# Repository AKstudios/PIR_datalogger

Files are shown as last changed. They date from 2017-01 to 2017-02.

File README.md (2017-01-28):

# PIR data logger
A motion/activity data logger that stores time-stamped data on a microSD card whenever there is motion within 3-5m. Approximate battery life: 1-2 years depending on LiPo battery used.

<p align="center">
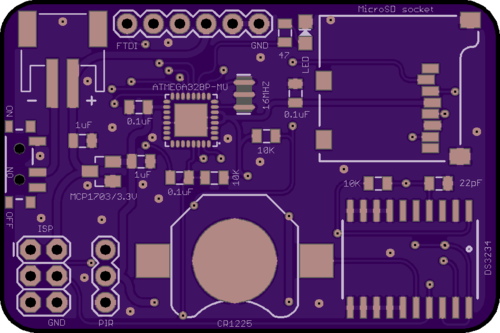
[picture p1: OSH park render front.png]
PIR datalogger - front
  
  <br></br>
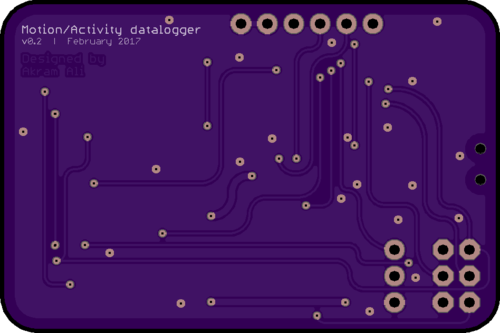
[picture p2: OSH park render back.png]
PIR datalogger - back
  
</p>

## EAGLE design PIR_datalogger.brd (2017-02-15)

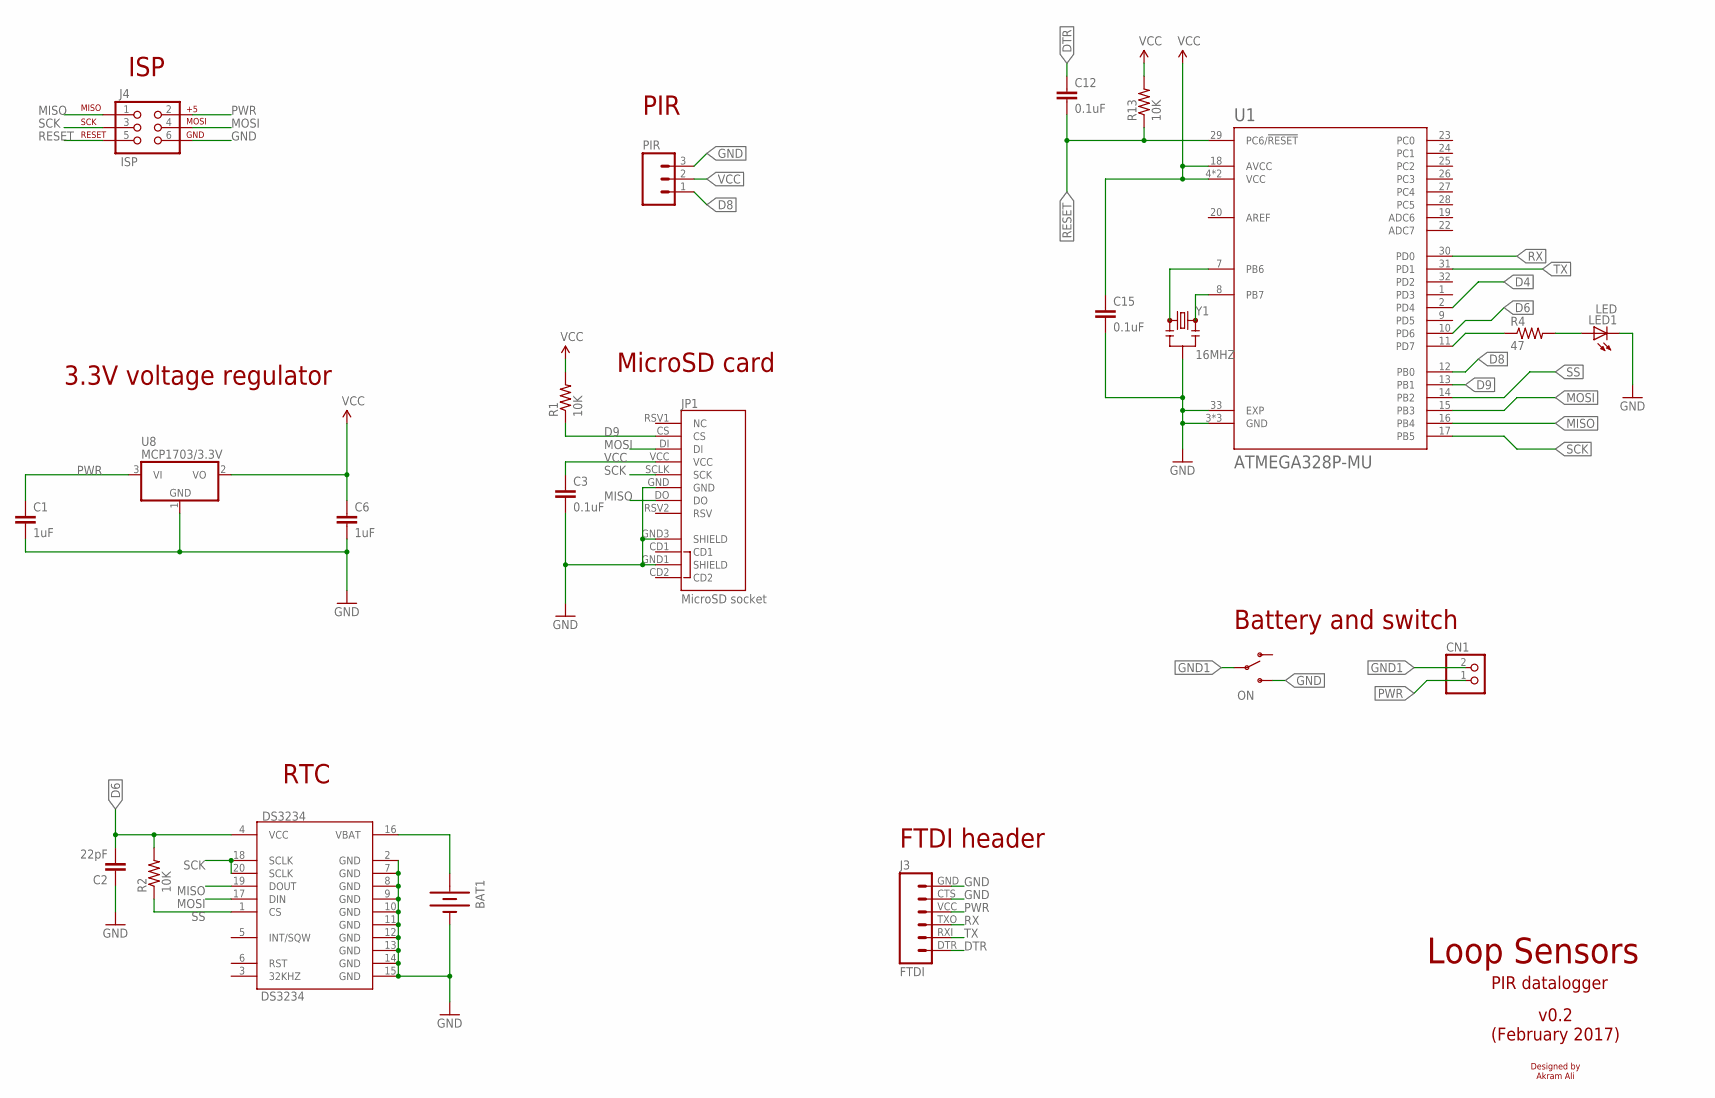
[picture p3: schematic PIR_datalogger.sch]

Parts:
BAT1: BATTERY12MM; BATTCON_12MM; MPN 3000
C1, C6: 1uF; 0805; MPN CC0805KKX7R7BB105
C2: 22pF; 0805; MPN AC0805KRX7R9BB104
C3, C12, C15: 0.1uF; 0805; MPN AC0805KRX7R9BB104
CN1: JST_2PIN-SMT-RA; JST-PH-2-SMT-RA
DS3234: DS3234; MPN DS3234S#
J3: FTDI; FTDI_BASIC
J4: ISP; 2X3
JP1: MicroSD socket; MICRO-SD-SOCKET-PP
LED1: LED; CHIPLED_0805; MPN 150080BS75000
ON: SWITCH-SPDT-SMD-A; SWITCH-SPST-SMD-A
PIR: M03PTH; 1X03
R1, R2, R13: 10K; 0805; MPN RC0805JR-0710KL
R4: 47; 0805; MPN RC0805JR-0747RL
U1: ATMEGA328P-MU; QFN50P500X500X100-33N
U8: MCP1703/3.3V; SOT23; MPN MCP1703T-2502E/CB
Y1: 16MHZ; RESONATOR-SMD; MPN CSTCE16M0V53-R0

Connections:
D4: U1.2 (PD4)
D6: C2.2, DS3234.4 (VCC), R2.2, U1.10 (PD6)
D8: PIR.1, U1.12 (PB0)
D9: JP1.CS, R1.1, U1.13 (PB1)
DTR: C12.1, J3.DTR (1)
GND: BAT1.GND (-), C1.2, C2.1, C3.2, C6.2, C15.2, DS3234.2 (GND), DS3234.7 (GND), DS3234.8 (GND), DS3234.9 (GND), DS3234.10 (GND), DS3234.11 (GND), DS3234.12 (GND), DS3234.13 (GND), DS3234.14 (GND), DS3234.15 (GND), J3.CTS (5), J3.GND (6), J4.6, JP1.GND, JP1.GND1 (SHIELD), JP1.GND3 (SHIELD), LED1.C, ON.3 (S), PIR.3, U1.3 (GND), U1.5 (GND), U1.21 (GND), U1.33 (EXP), U8.1 (GND), Y1.2
GND1: CN1.2 (1), ON.2
MISO: DS3234.19 (DOUT), J4.1, JP1.DO, U1.16 (PB4)
MOSI: DS3234.17 (DIN), J4.4, JP1.DI, U1.15 (PB3)
unnamed: R4.1, U1.11 (PD7)
unnamed: LED1.A, R4.2
unnamed: U1.8 (PB7), Y1.3
unnamed: U1.7 (PB6), Y1.1
unnamed: BAT1.PWR@1 (+), DS3234.16 (VBAT)
PWR: C1.1, CN1.1 (2), J3.VCC (4), J4.2, U8.3 (VI)
RESET: C12.2, J4.5, R13.1, U1.29 (PC6/!RESET)
RX: J3.TXO (3), U1.30 (PD0)
SCK: DS3234.18 (SCLK), DS3234.20 (SCLK), J4.3, JP1.SCLK (SCK), U1.17 (PB5)
SS: DS3234.1 (CS), R2.1, U1.14 (PB2)
TX: J3.RXI (2), U1.31 (PD1)
VCC: C3.1, C6.1, C15.1, JP1.VCC, PIR.2, R1.2, R13.2, U1.4 (VCC), U1.6 (VCC), U1.18 (AVCC), U8.2 (VO)

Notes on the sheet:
ISP
3.3V voltage regulator
Loop Sensors
PIR datalogger
v0.2 (February 2017)
Designed by Akram Ali
MicroSD card
RTC
PIR
FTDI header
Battery and switch

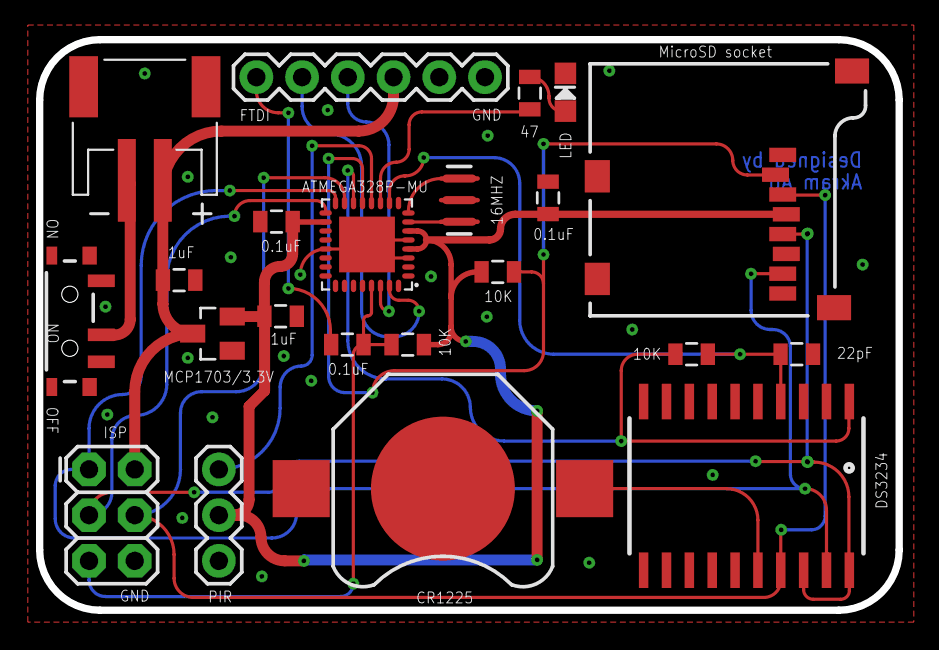
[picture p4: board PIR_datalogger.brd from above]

Board: 2 copper layers, 47.8 x 31.7 mm, 22 parts (0 on the bottom side), 20 nets.

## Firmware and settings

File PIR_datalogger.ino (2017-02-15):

//****************************************************************

// OSBSS PIR motion sensor datalogger - v0.01
// Last edited on March 30, 2015

//****************************************************************

#include <PowerSaver.h>
#include <DS3234lib3.h>
#include <SdFat.h>
#include <EEPROM.h>

// Global objects and variables   ******************************
char filename[15] = "log.csv";    // Filename. Format: "12345678.123". Cannot be more than 8 characters in length, contain spaces or start with a number

PowerSaver chip; // declare object for PowerSaver class
DS3234 RTC;      // declare object for DS3234 class
SdFat sd;        // declare object for SdFat class
SdFile myFile;     // declare object for SdFile class

#define POWER 4        // pin 4 supplies power to microSD card breakout
#define RTCPOWER 6     // pin 6 supplies power to DS3234 RTC breakout
#define LED 7          // pin 7 controls LED
int chipSelect = 9;       // pin 9 is micrSD card breakout CS pin
int state = 0;         // this variable stores the state of PIR sensor's output (either 1 or 0)

// ISR ****************************************************************
ISR(PCINT0_vect)  // Interrupt Service Routine for PCINT0 vector (pin 8)
{
  asm("nop");  // do nothing
}

// Main code ****************************************************************
void setup()
{
  Serial.begin(19200); // open serial at 19200 bps
  Serial.println("setup");
  delay(10);
  
  pinMode(POWER, OUTPUT); // set output pins
  pinMode(RTCPOWER, OUTPUT);
  pinMode(LED, OUTPUT);
  
  digitalWrite(POWER, HIGH);     // turn on SD card
  digitalWrite(RTCPOWER, HIGH);     // turn on RTC
  delay(1);                      // give some delay to ensure SD card is turned on properly
  
  if(!sd.begin(chipSelect, SPI_HALF_SPEED))  // initialize microSD card
  {
    SDcardError(3);
  }
  else
  {
    // open the file for write at end like the Native SD library
    if(!myFile.open(filename, O_RDWR | O_CREAT | O_AT_END))
    {
      SDcardError(2);
    }

    else
    {    
      myFile.println();
      myFile.println("Date/Time,Occupancy");
      myFile.println();
      myFile.close();
      
      digitalWrite(LED, HIGH);
      delay(10);
      digitalWrite(LED, LOW);
    }
  }
  chip.sleepInterruptSetup();    // setup sleep function & pin change interrupts on the ATmega328p. Power-down mode is used here
}

void loop()
{
  digitalWrite(POWER, LOW);  // turn off SD card
  digitalWrite(RTCPOWER, LOW);     // turn off RTC
  delay(1);
  
  chip.turnOffADC();  // turn off ADC to save power
  chip.turnOffSPI();  // turn off SPI bus to save power
  chip.turnOffWDT();  // turn off WatchDog timer. This doesn't work for Pro Mini (Rev 11); only works for Arduino Uno
  chip.turnOffBOD();

  chip.goodNight();    // put the processor in power-down mode
  
  // code will resume from here once the processor wakes up ============== //
  chip.turnOnADC();   // turn on ADC once the processor wakes up
  chip.turnOnSPI();   // turn on SPI bus once the processor wakes up
  delay(1);    // important delay to ensure SPI bus is properly activated
  
  digitalWrite(POWER, HIGH);  // turn on SD card
  digitalWrite(RTCPOWER, HIGH);     // turn on RTC
  delay(1);    // give some delay to ensure SD card is turned on properly
  
  RTC.checkDST(); // check and account for Daylight Savings Time in US
  
  printToSD(); // print data to SD card
}

void printToSD()
{
  String time = RTC.timeStamp();    // get date and time from RTC
  Serial.println(time);
  delay(10);
  
  if(!sd.begin(chipSelect, SPI_HALF_SPEED))
  {
    SDcardError(3);
  }
  else
  {
    if(!myFile.open(filename, O_RDWR | O_CREAT | O_AT_END))
    {
      SDcardError(2);
    }
  
    else
    {
      state = digitalRead(8); // read current state of PIR. 1 = movement detected, 0 = no movement.
      
      if(state == 1)
      {
        myFile.print(time);
        myFile.print(",");
        myFile.print("0");
        myFile.println();
        myFile.print(time);
        myFile.print(",");
        myFile.print("1");
      }
      else if(state == 0)
      {
        myFile.print(time);
        myFile.print(",");
        myFile.print("1");
        myFile.println();
        myFile.print(time);
        myFile.print(",");
        myFile.print("0");
      }
      myFile.println();
      myFile.close();    // close file - very important
                       // give some delay by blinking status LED to wait for the file to properly close
      digitalWrite(LED, HIGH);
      delay(10);
      digitalWrite(LED, LOW);
    }
  }
}

// SD card Error response  ****************************************************************
void SDcardError(int n)
{
    for(int i=0;i<3;i++)   // blink LED 3 times to indicate SD card write error; 2 to indicate file read error
    {
      digitalWrite(LED, HIGH);
      delay(50);
      digitalWrite(LED, LOW);
      delay(150);
    }
}

//****************************************************************

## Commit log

2017-01-27 Added EAGLE files
    [PIR_datalogger.brd, PIR_datalogger.sch]
2017-02-15 v0.2 - design changes
    * Removed NPN transistor - microSD cards use their own sleep mode -
    keeping up with new SD protocol
    * Added decoupling cap to microSD card
    * Added pullups to microSD card and RTC
    * Adjusted some traces
    [PIR_datalogger.brd, PIR_datalogger.sch]

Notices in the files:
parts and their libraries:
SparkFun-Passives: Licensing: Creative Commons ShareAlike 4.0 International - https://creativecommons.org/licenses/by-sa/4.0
